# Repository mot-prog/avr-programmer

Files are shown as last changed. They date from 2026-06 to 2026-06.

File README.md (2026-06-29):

# AVR ISP Programmer



> Because this was a french project, most of the code was written in French

A custom In-System Programmer (ISP) designed to flash AVR microcontrollers via USB. This project encompasses the full stack: custom hardware design (PCB), USB firmware (LUFA), and a host PC tool (libusb).

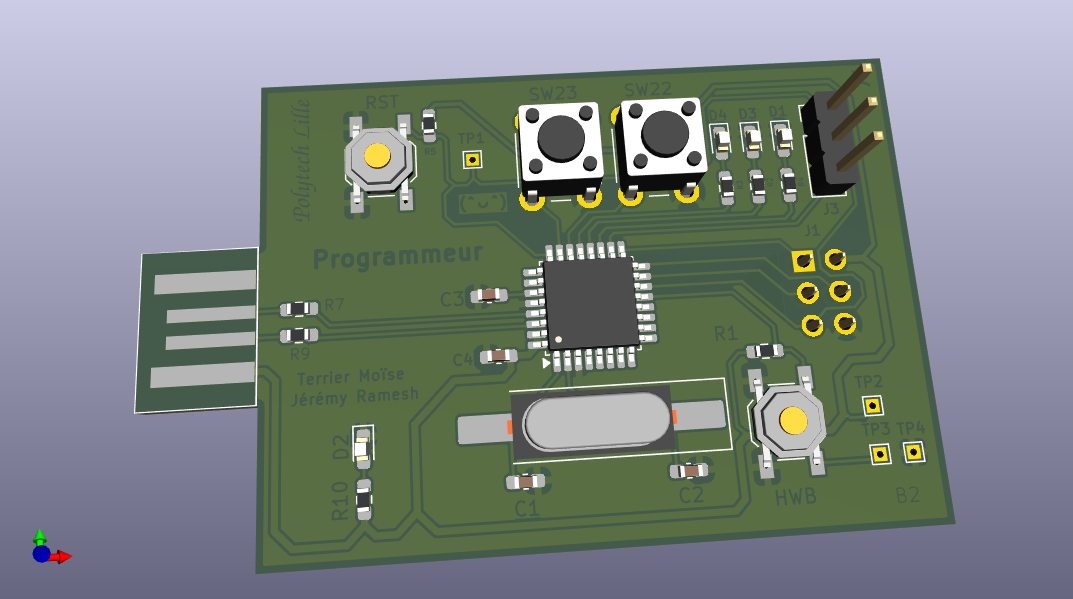
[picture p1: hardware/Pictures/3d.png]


## Features

- **Custom PCB:** Designed with KiCad, featuring an ATmega16U2 microcontroller.
- **Low-Level USB Communication:** Replaces the standard CDC class with raw IN/OUT endpoints using the LUFA stack.
- **SPI ISP Protocol:** Implements the Atmel AVR910 specification for reading device signatures and erasing/writing flash memory.
- **Page Mode Writing:** Supports modern AVR targets (like ATmega328P) using SPI page-mode flashing.
- **CLI Host Tool:** A custom C program using `libusb-1.0` to parse Intel HEX files and flash targets directly from a Linux terminal.

## Architecture

### 1. Hardware (`/hardware`)

The board is built around an ATmega16U2. It exposes a standard ISP interface (MISO, MOSI, SCK, RESET) to connect to target AVRs.

- Includes status LEDs and user buttons.
- KiCad schematics and PCB routing files are available in the `hardware/` directory.

### 2. Firmware (`/firmware`)

The brain of the programmer. Written in C using the [LUFA](http://www.fourwalledcubicle.com/LUFA.php) library.

- Processes `OUT` packets from the PC to execute SPI commands.
- Transmits AVR responses (signatures, flash reads) back to the PC via `IN` packets.

### 3. PC Software (`/software`)

A Linux command-line interface written in C.

- Communicates with the ATmega16U2 via `libusb-1.0`.
- Parses `.hex` files.
- Includes a dynamic target database to adjust page sizes and memory limits based on the detected target's ISP signature.

### 3. Tests (`/ISP_tests`)

Functions to test the hardware by ISP:

- `boutons.c`: test the boutons

## Installation & Build

### Prerequisites

You need the AVR toolchain and libusb installed on your system:

- Arch based

```bash
sudo pacman -S avr-gcc avr-libc avrdude libusb
```

- Debian based

```bash
sudo apt-get install gcc-avr avr-libc avrdude libusb-dev
```

### Building the Project

A root Makefile orchestrates the cross-compilation for both the PC host and the AVR firmware.

```bash
# Build firmware, PC software, and test examples
make all
```

### Flashing the Programmer Firmware

Connect the programmer to your PC via USB. Put the ATmega16U2 board into **DFU mode** (Hardware RESET), then flash the compiled LUFA firmware:

- For minicom (debugging):

```bash
make minicom
```

- For the main program

```bash
make prog
```

> Unplugging and replugging the USB cable it sometimes necessary to detect the AVR with the new firmawre.

## Usage

Connect the programmer to your PC via USB, and wire the ISP header to your target AVR (e.g., an Arduino Uno / ATmega328P).

**1. Where you put your C files**
In `code_to_flash` you put your C files. When you compile all the files (`make`) your C files are stored in the `hex` folder.

**2. Read Target Flash:**

```bash
make read
```

> Usefull to be sure that the code is properly written into the card

**3. Write Hex File to Target:**

```bash
# Example
make write hex/blind.hex
```

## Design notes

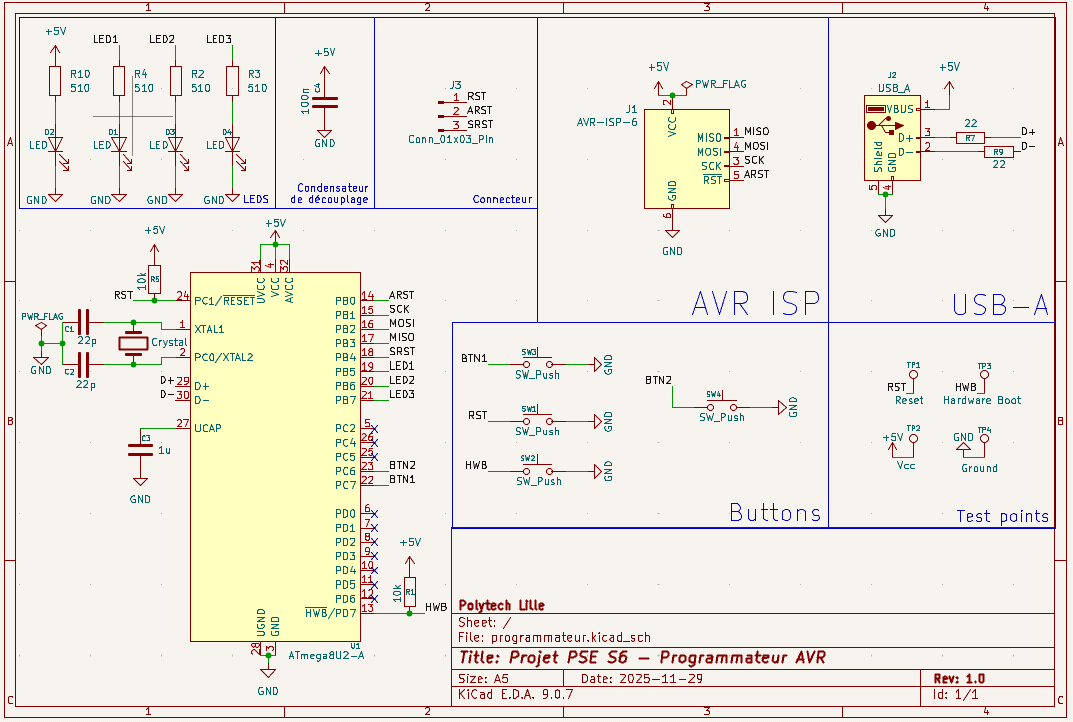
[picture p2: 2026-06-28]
hardware/Pictures/Schema.png

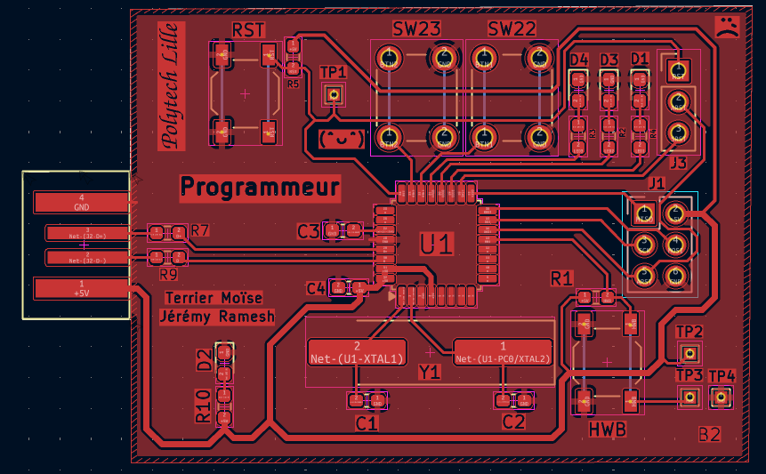
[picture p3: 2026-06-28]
hardware/Pictures/routage_corrige.png

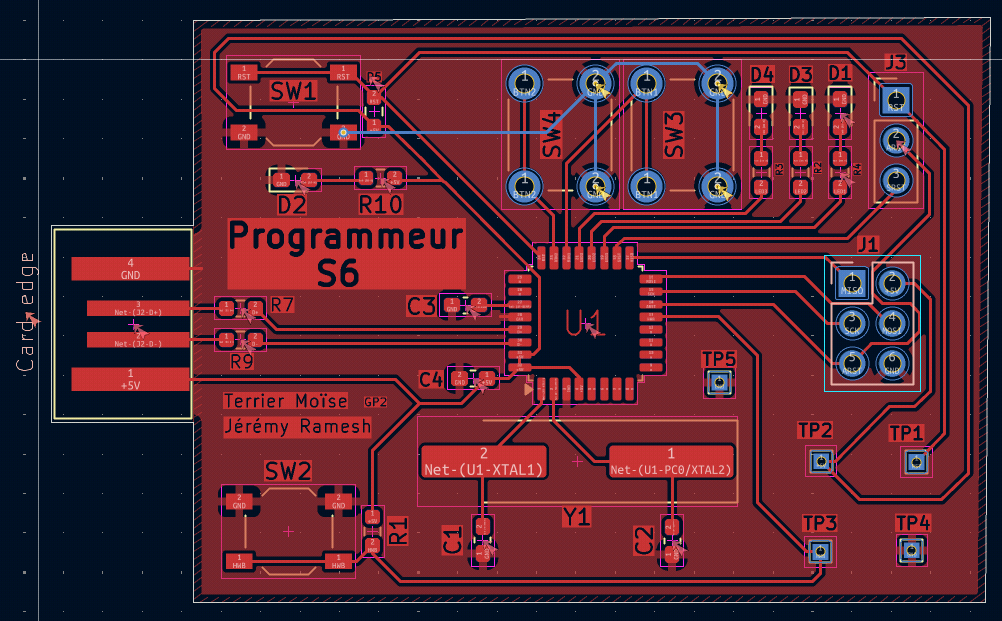
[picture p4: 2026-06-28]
hardware/Pictures/routage.png

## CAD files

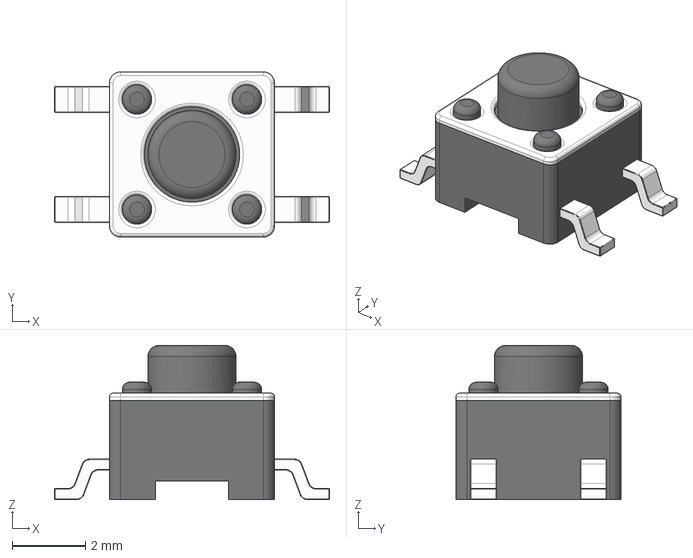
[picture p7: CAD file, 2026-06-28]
hardware/3D Model/Tact Switch 4.5mm SMT.step
7.50 x 4.50 x 4.20 mm

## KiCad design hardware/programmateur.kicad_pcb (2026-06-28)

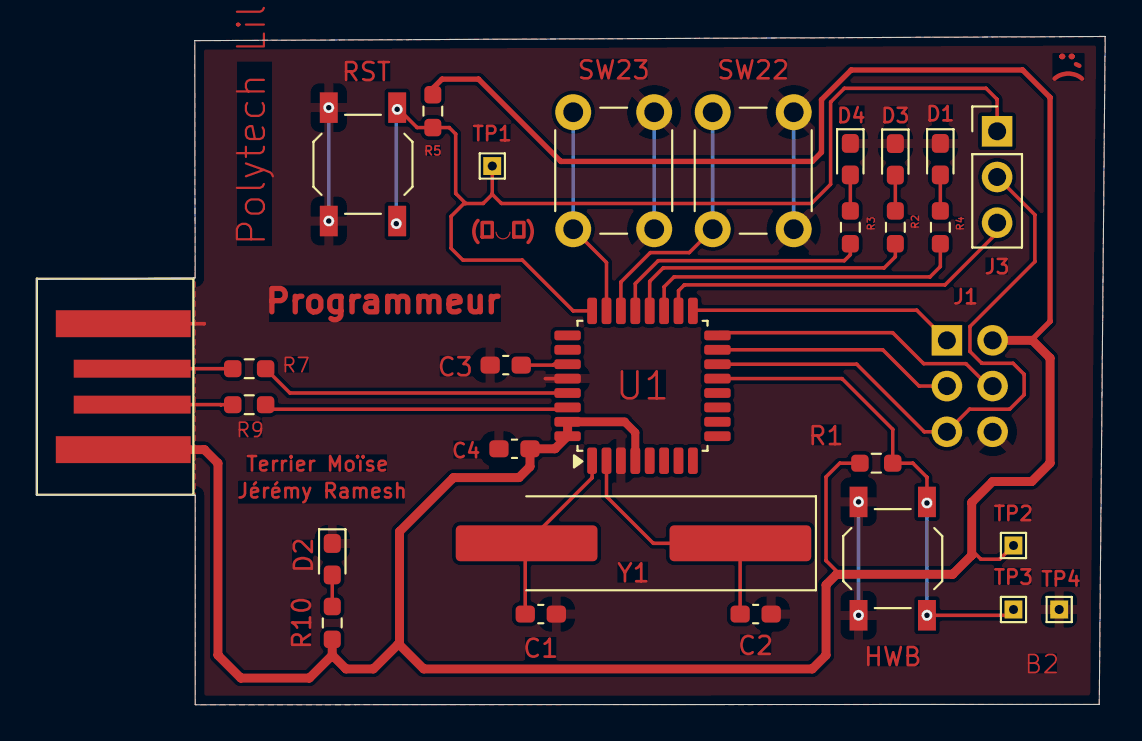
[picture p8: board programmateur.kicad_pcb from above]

Board: 2 copper layers, 59.4 x 37.1 mm, 29 parts (1 on the bottom side), 25 nets.

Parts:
C1, C2: 22p; C_0603_1608Metric_Pad1.08x0.95mm_HandSolder
C3: 1u; C_0603_1608Metric_Pad1.08x0.95mm_HandSolder
C4: 100n; C_0603_1608Metric_Pad1.08x0.95mm_HandSolder
D1, D2, D3, D4: LED; LED_0603_1608Metric_Pad1.05x0.95mm_HandSolder
HWB: SW_Push; SW_SPST_TL3342
J1: AVR-ISP-6; PinSocket_2x03_P2.54mm_Vertical
J2: USB_A; USB-A-PCB
J3: Conn_01x03_Pin; PinHeader_1x03_P2.54mm_Vertical
R1, R5: 10k; R_0603_1608Metric_Pad0.98x0.95mm_HandSolder
R2, R3, R4, R10: 510; R_0603_1608Metric_Pad0.98x0.95mm_HandSolder
R7, R9: 22; R_0603_1608Metric_Pad0.98x0.95mm_HandSolder
RST: SW_Push; SW_SPST_TL3342
SW22, SW23: SW_Push; SW_PUSH_6mm_H4.3mm
TP1: Reset; TestPoint_THTPad_1.0x1.0mm_Drill0.5mm
TP2: Vcc; TestPoint_THTPad_1.0x1.0mm_Drill0.5mm
TP3: Hardware Boot; TestPoint_THTPad_1.0x1.0mm_Drill0.5mm
TP4: Ground; TestPoint_THTPad_1.0x1.0mm_Drill0.5mm
U1: ATmega8U2-A; TQFP-32_7x7mm_P0.8mm
Y1: Crystal; Crystal_SMD_HC49-SD_HandSoldering

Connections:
+5V: C4.1, J1.2 (VCC), J2.1 (VBUS), R1.1, R5.1, R10.2, TP2.1, U1.4 (VCC), U1.31 (UVCC), U1.32 (AVCC)
/ARST: J1.5 (~RST), J3.2, U1.14 (PB0)
/BTN1: SW22.1, U1.22 (PC7)
/BTN2: SW23.1, U1.23 (PC6)
/D+: R7.2, U1.29 (D+)
/D-: R9.2, U1.30 (D-)
/HWB: HWB.1, R1.2, TP3.1, U1.13 (~HWB/PD7)
/LED1: R4.2, U1.19 (PB5)
/LED2: R2.2, U1.20 (PB6)
/LED3: R3.2, U1.21 (PB7)
/MISO: J1.1 (MISO), U1.17 (PB3)
/MOSI: J1.4 (MOSI), U1.16 (PB2)
/RST: J3.1, R5.2, RST.1, TP1.1, U1.24 (PC1/~RESET)
/SCK: J1.3 (SCK), U1.15 (PB1)
/SRST: J3.3, U1.18 (PB4)
GND: C1.1, C2.1, C3.1, C4.2, D1.1 (K), D2.1 (K), D3.1 (K), D4.1 (K), HWB.2, J1.6 (GND), J2.4 (GND), RST.2, SW22.2, SW23.2, TP4.1, U1.3 (GND), U1.28 (UGND)
unnamed: D1.2 (A), R4.1
unnamed: D2.2 (A), R10.1
unnamed: D3.2 (A), R2.1
unnamed: D4.2 (A), R3.1
unnamed: J2.3 (D+), R7.1
unnamed: J2.2 (D-), R9.1
unnamed: C2.2, U1.2 (PC0/XTAL2), Y1.1
unnamed: C3.2, U1.27 (UCAP)
unnamed: C1.2, U1.1 (XTAL1), Y1.2

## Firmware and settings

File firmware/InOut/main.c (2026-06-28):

#include <avr/io.h>
#include <avr/wdt.h>
#include <avr/power.h>
#include <avr/interrupt.h>
#include <string.h>
#include <stdio.h>
#include <util/delay.h>
#include "Descriptors.h"
#include <LUFA/Drivers/USB/USB.h>

#define SPI_DDR DDRB
#define SPI_PORT PORTB
#define SPI_SS PB0
#define SPI_SCK PB1
#define SPI_MOSI PB2
#define SPI_MISO PB3

void EVENT_USB_Device_ConfigurationChanged(void);
void ProcessOUT(void);
void ProcessIN(void);
void spi_init(void);
void spi_ON(void);
void spi_OFF(void);
void ProcessIN_Flash(void);
uint8_t spi_transfer(uint8_t data);
void chip_erase(void);

uint8_t commande_PC = 0;
uint16_t flash_address = 0;

int main(void)
{
	/*Initialisation du matériel */
	// LEDS
	DDRB |= (1 << 5) | (1 << 6) | (1 << 7);
	PORTB &= ~((1 << 5) | (1 << 6) | (1 << 7)); // OFF
	// BUTTONS
	DDRC &= ~((1 << 6) | (1 << 7));
	PORTC |= (1 << 6) | (1 << 7);

	/*Initialisation de la pile USB LUFA */
	USB_Init();
	GlobalInterruptEnable();
	spi_init();

	for (;;)
	{
		USB_USBTask();

		// SÉCURITÉ : On ne fait rien si le périphérique n'est pas encore configuré par le PC
		if (USB_DeviceState != DEVICE_STATE_Configured)
			continue;

		ProcessOUT();
		ProcessIN();
	}
}

void EVENT_USB_Device_ConfigurationChanged(void)
{
	// Configuration du point d'accès pour recevoir les ordres (LEDs)
	Endpoint_ConfigureEndpoint(DATA_OUT_EPADDR, EP_TYPE_INTERRUPT, DATA_SIZE, 1);
	// Configuration du point d'accès pour envoyer les données (Boutons/ISP)
	Endpoint_ConfigureEndpoint(DATA_IN_EPADDR, EP_TYPE_INTERRUPT, DATA_SIZE, 1);
}

void ProcessOUT(void)
{
	Endpoint_SelectEndpoint(DATA_OUT_EPADDR);
	if (Endpoint_IsOUTReceived())
	{
		if (Endpoint_IsReadWriteAllowed())
		{
			// On lit l'octet envoyé par le PC
			commande_PC = Endpoint_Read_8();

			if (commande_PC == 0x02) // Lecture flash (flash_read.c)
			{
				flash_address = ((uint16_t)Endpoint_Read_8() << 8); // Poids fort
				flash_address |= Endpoint_Read_8();					// Poids faible
			}

			else if (commande_PC == 0x03) // Ecriture de flash (flash_rw.c)
			{
				flash_address = ((uint16_t)Endpoint_Read_8() << 8); // Poids fort
				flash_address |= Endpoint_Read_8();					// Poids faible
				uint8_t low = Endpoint_Read_8();
				uint8_t high = Endpoint_Read_8();

				spi_ON();
				_delay_ms(5); // Temps de réveil cible

				// (3.2 datasheet) Enable Memory Access
				spi_transfer(0xAC);
				spi_transfer(0x53);
				spi_transfer(0x00);
				spi_transfer(0x00);

				// Low byte
				spi_transfer(0x40);
				spi_transfer(flash_address >> 8);
				spi_transfer(flash_address & 0xFF);
				spi_transfer(low);

				// High byte
				spi_transfer(0x48);
				spi_transfer(flash_address >> 8);
				spi_transfer(flash_address & 0xFF);
				spi_transfer(high);

				// Write
				spi_transfer(0x4C);
				spi_transfer(flash_address >> 8);
				spi_transfer(flash_address & 0xFF);
				spi_transfer(0x00);

				_delay_ms(5); // Attente de la gravure physique
				spi_OFF();
			}
			else if (commande_PC == 0x04)
			{
				chip_erase();
			}
			else if (commande_PC != 0x01)
			{
				PORTB = commande_PC; // Gestion des LEDs
			}
		}
		Endpoint_ClearOUT();
	}
}

void ProcessIN(void)
{
	Endpoint_SelectEndpoint(DATA_IN_EPADDR);
	if (Endpoint_IsReadWriteAllowed())
	{
		if (commande_PC == 0x02)
		{
			spi_ON();

			// (3.2 datasheet) Enable Memory Access
			spi_transfer(0xAC);
			spi_transfer(0x53);
			spi_transfer(0x00);
			spi_transfer(0x00);

			for (uint16_t i = 0; i < 4; i++)
			{
				uint16_t current_addr = flash_address + i;

				// Lecture du Low Byte
				spi_transfer(0x20);
				spi_transfer(current_addr >> 8);   // On décale de 8 les 2 octets donc on a 0x00HIGH = 0xHIGH
				spi_transfer(current_addr & 0xFF); // On fait un & à l'adresse avec 0x00FF donc on a 0x00LOW = 0xLOW
				uint8_t data_low = spi_transfer(0x00);

				// Lecture du High Byte
				spi_transfer(0x28);
				spi_transfer(current_addr >> 8);
				spi_transfer(current_addr & 0xFF);
				uint8_t data_hight = spi_transfer(0x00);

				// envoie au PC
				Endpoint_Write_8(data_low);
				Endpoint_Write_8(data_hight);
			}
			spi_OFF();
			commande_PC = 0; // On a fini d'envoyer le bloc
		}
		else if (commande_PC == 0x01) // isp_ids.c
		{
			{
				// Mode ISP : Le PC a demandé les identifiants
				spi_ON();

				// (3.2 datasheet) Enable Memory Access
				spi_transfer(0xAC);
				spi_transfer(0x53);
				spi_transfer(0x00);
				spi_transfer(0x00);

				// --- Lecture du 1er octet de signature (Adresse 0x00) ---
				spi_transfer(0x30);
				spi_transfer(0x00);
				spi_transfer(0x00);
				uint8_t data_1 = spi_transfer(0x00); // La cible répond pendant cet octet

				// --- Lecture du 2ème octet de signature (Adresse 0x01) ---
				spi_transfer(0x30);
				spi_transfer(0x00);
				spi_transfer(0x01);
				uint8_t data_2 = spi_transfer(0x00);

				// --- Lecture du 3ème octet de signature (Adresse 0x02) ---
				spi_transfer(0x30);
				spi_transfer(0x00);
				spi_transfer(0x02);
				uint8_t data_3 = spi_transfer(0x00);

				spi_OFF();

				// On envoie les 3 octets au PC
				Endpoint_Write_8(data_1);
				Endpoint_Write_8(data_2);
				Endpoint_Write_8(data_3);

				commande_PC = 0;
			}
		}
		// commandes boutons
		else
			Endpoint_Write_8(PINC & 0xC0);

		Endpoint_ClearIN();
	}
}

void spi_init(void)
{
	SPI_DDR |= (1 << SPI_MOSI) | (1 << SPI_SCK) | (1 << SPI_SS); // Définition des sorties
	SPI_DDR &= ~(1 << SPI_MISO);								 // Définition de l'entrée
	SPI_PORT |= (1 << SPI_SS);									 // Désactivation du périphérique
	SPCR = (1 << SPE) | (1 << MSTR) | (1 << SPR1) | (1 << SPR0); // Activation SPI (SPE) en état maître (MSTR)
	SPSR &= ~(1 << SPI2X);										 // horloge F_CPU/128 (SPI2X=0, SPR1=1,SPR0=1)
}

void spi_ON(void) // Activer le périphérique
{
	SPI_PORT &= ~(1 << SPI_SS); // Ligne SS à l'état bas
}

void spi_OFF(void) // Désactiver le périphérique
{
	SPI_PORT |= (1 << SPI_SS); // Ligne SS à l'état haut
}

uint8_t spi_transfer(uint8_t data)
{
	SPDR = data; // Octet a envoyer
	while (!(SPSR & (1 << SPIF)))
		; // Attente fin envoi (drapeau SPIF du statut)
	return SPDR;
}

void chip_erase(void)
{
	spi_ON();
	_delay_ms(5);
	// (3.2 datasheet) Enable Memory Access
	spi_transfer(0xAC);
	spi_transfer(0x53);
	spi_transfer(0x00);
	spi_transfer(0x00);
	// (3.4.3 datasheet) erase
	spi_transfer(0xAC);
	spi_transfer(0x80);
	spi_transfer(0x00);
	spi_transfer(0x00);
	_delay_ms(5);
	spi_OFF();
}

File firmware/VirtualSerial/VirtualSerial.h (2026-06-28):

/*
			 LUFA Library
	 Copyright (C) Dean Camera, 2021.

  dean [at] fourwalledcubicle [dot] com
		   www.lufa-lib.org
*/

/*
  Copyright 2021  Dean Camera (dean [at] fourwalledcubicle [dot] com)

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
  The author disclaims all warranties with regard to this
  software, including all implied warranties of merchantability
  and fitness.  In no event shall the author be liable for any
  special, indirect or consequential damages or any damages
  whatsoever resulting from loss of use, data or profits, whether
  in an action of contract, negligence or other tortious action,
  arising out of or in connection with the use or performance of
  this software.
*/

/** \file
 *
 *  Header file for VirtualSerial.c.
 */

#ifndef _VIRTUALSERIAL_H_
#define _VIRTUALSERIAL_H_

/* Includes: */
#include <avr/io.h>
#include <avr/wdt.h>
#include <avr/power.h>
#include <avr/interrupt.h>
#include <string.h>
#include <stdio.h>

#include "Descriptors.h"

#include <LUFA/Drivers/Board/LEDs.h>
#include <LUFA/Drivers/Board/Joystick.h>
#include <LUFA/Drivers/USB/USB.h>
#include <LUFA/Platform/Platform.h>

/* Macros: */
/** LED mask for the library LED driver, to indicate that the USB interface is not ready. */
#define LEDMASK_USB_NOTREADY LEDS_LED1

/** LED mask for the library LED driver, to indicate that the USB interface is enumerating. */
#define LEDMASK_USB_ENUMERATING (LEDS_LED2 | LEDS_LED3)

/** LED mask for the library LED driver, to indicate that the USB interface is ready. */
#define LEDMASK_USB_READY (LEDS_LED2 | LEDS_LED4)

/** LED mask for the library LED driver, to indicate that an error has occurred in the USB interface. */
#define LEDMASK_USB_ERROR (LEDS_LED1 | LEDS_LED3)

/* Function Prototypes: */
void SetupHardware(void);
void CheckButtons(void);
int Button_Status(int boutton);

void EVENT_USB_Device_Connect(void);
void EVENT_USB_Device_Disconnect(void);
void EVENT_USB_Device_ConfigurationChanged(void);
void EVENT_USB_Device_ControlRequest(void);

#endif
